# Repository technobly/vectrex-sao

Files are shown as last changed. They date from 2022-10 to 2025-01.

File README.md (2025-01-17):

# Vectrex SAO

Hardware and software files for the mini playable Vectrex SAO by Brett Walach.  Made for Hackaday Supercon 2022!

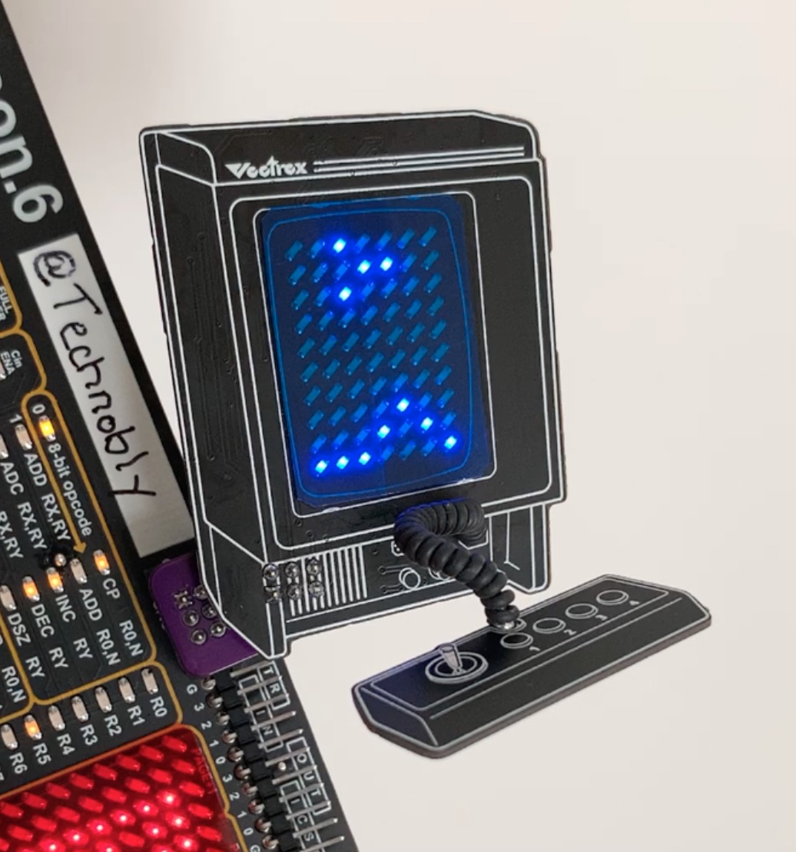
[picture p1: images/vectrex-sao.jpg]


# Features
- Mini playable low res version of Scramble
- 7 x 10 White LED Charlieplexed display (placed in a slight perspective to match the Vectrex artwork!)
- Joystick is a 1-button capacitive touch controller
- PIC16F886 8K MCU (I had a reel of these I pulled out of the trash, which is why it uses this relatively old and huge MCU.)
- Speaker (auto mutes if not playing, or can permanently disable with removing a solder blob)
- Coily cord!  This is made of a solid core silicone wire, and stranded core silicone wire.  These were an absolute pain to make.
- Jumpers for hacking, control it via I2C directly if you want from a main badge... and there's PWM input for the speaker and touch controller output for sensing button presses available to wire to the SAO connector.
- What's a Vectrex? [https://wikipedia.org/wiki/Vectrex](https://wikipedia.org/wiki/Vectrex)
- **High score permanently saved!** Tweet a pic of your score @Technobly #vectrex-sao #supercon #badgelife

# BOM

- PCBs: 1.0mm, HASL finish, white silkscreen, black soldermask, gives a nice thin feel to them. NOTE: 1.0mm is thinner than standard PCBs!
- Don't forget to order both PCBs: 1) the main [console body](gerbers/vectrex-sao-v1.1.zip) and 2) the [controller](gerbers/vectrex-sao-controller-v1.1.zip)
- [bom/vectrex-sao-bom-both-sides.csv](bom/vectrex-sao-bom-both-sides.csv) contains all parts required to build the SAO, ready to upload to JLCPCB
- [bom/vectrex-sao-pos-both-sides.csv](bom/vectrex-sao-pos-both-sides.csv) contains the position of all parts required, ready to upload to JLCPCB
- Inner coily cord wire - 18 AWG solid core, black PVC jacket, outer diameter 1.6mm, 2.0" long with 0.25" stripped on both ends for a 1.5" long jacket. [Digikey 10982-18-1-2000-001-1-TD](https://www.digikey.com/en/products/detail/cnc-tech/10982-18-1-2000-001-1-TD/12749485)
- Outer coily cord wire - 26 AWG stranded core, black silicone jacket, outer diameter 1.3mm, ~27 turns, ~9" long. [Digikey 1175-3132-26-1-0500-001-1-TS-DS-ND](https://www.digikey.com/en/products/detail/cnc-tech/3132-26-1-0500-001-1-TS/15853654)

# Coily Cord Construction

#### 1. Wrap the 26 AWG stranded silicone wire around the 0.25" stripped end of the 18 AWG solid wire, but do not solder it yet.

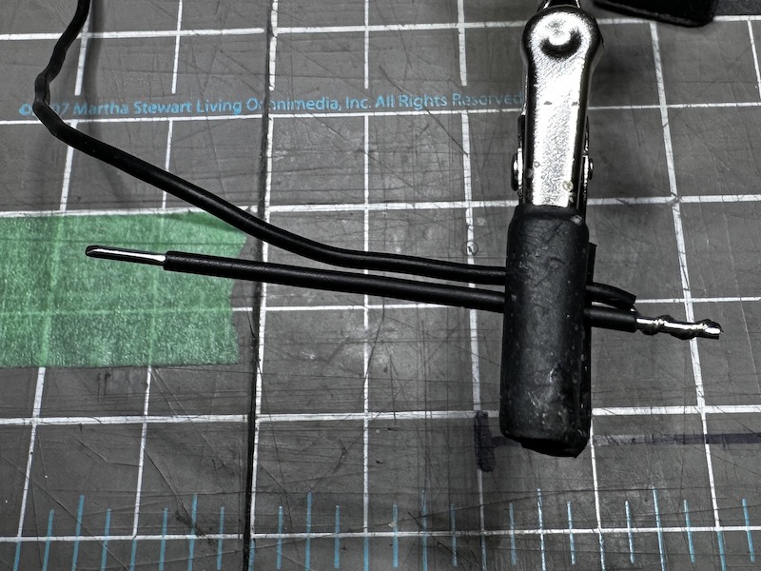
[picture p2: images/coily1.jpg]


#### 2. Add the controller PCB observing the proper orientation.

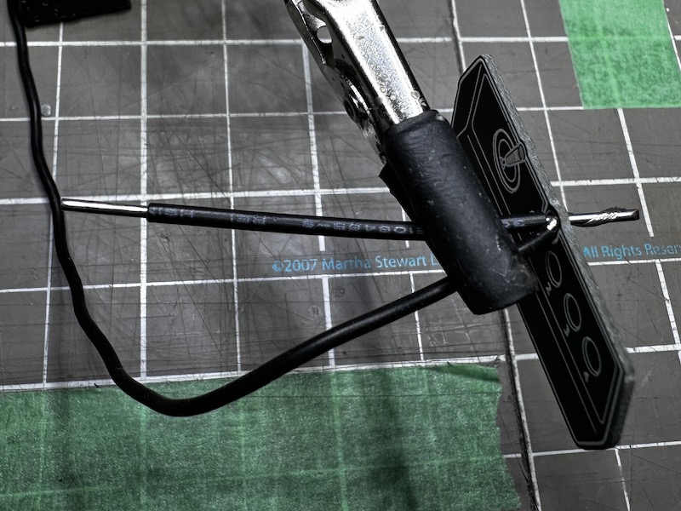
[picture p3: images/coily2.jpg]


#### 3. Add a good amount of solder here, and push the board up against the wire bundle if possible (I did not push it up in this picture like I should have).

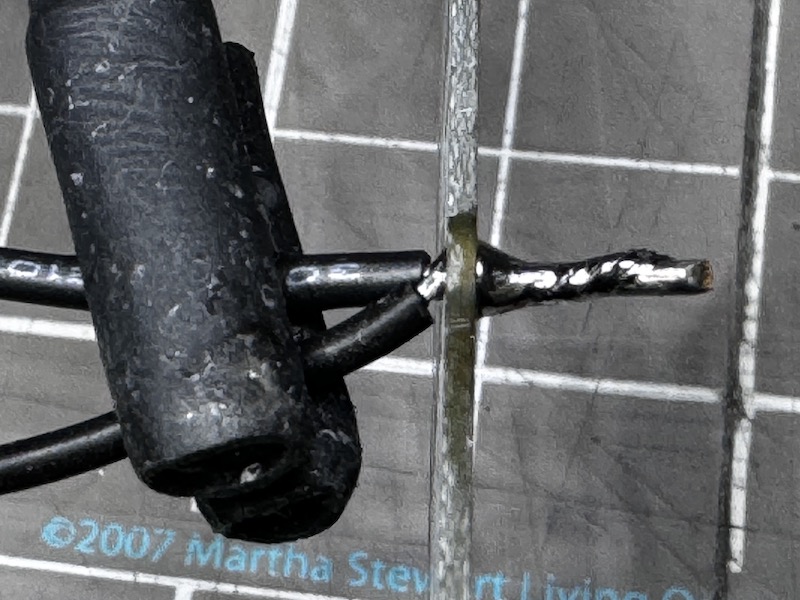
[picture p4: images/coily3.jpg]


#### 4. Flush cut the excess wire, but leave a bit sticking out so has a little mechanical strength.

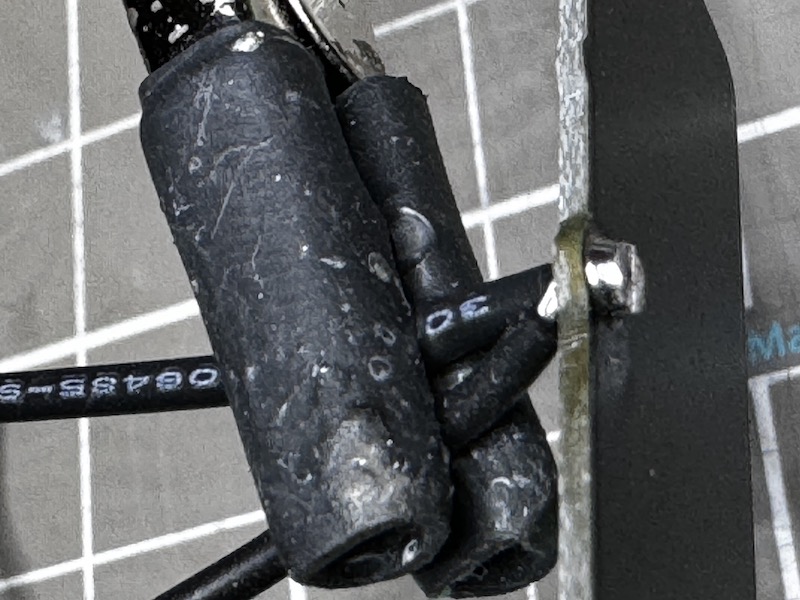
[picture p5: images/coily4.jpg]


#### 5. Wrap the silicone wire 21-27 times (21 if diameter is 1.5mm, 27 if 1.3mm).  Wrap the wire tightly and keep pushing it down on the solid core as you go.  Finally twist the stranded wires around the end and while holding that tightly, clamp the wire bundle to prevent it from unwinding.

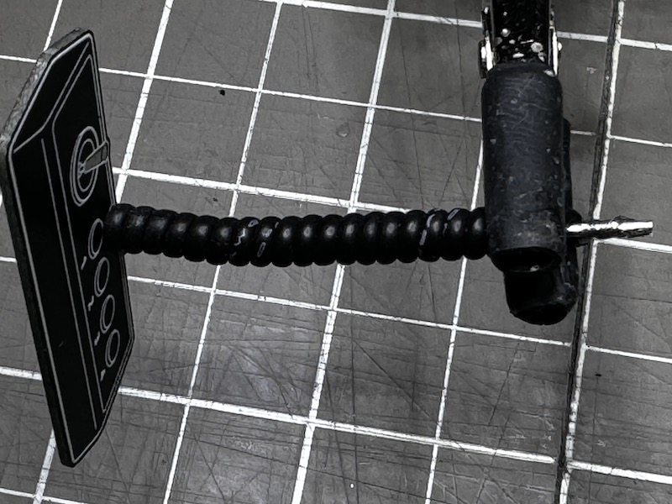
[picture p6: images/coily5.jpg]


#### 6. Now add the main PCB obsererving the correct orientation.

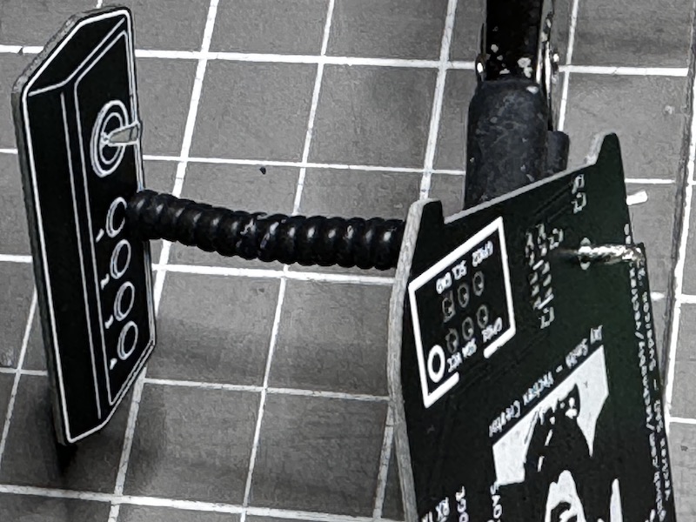
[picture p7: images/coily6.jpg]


#### 7. Add a good amount of solder here as well. Flush cut the excess wire, but leave a bit sticking out so has a little mechanical strength.

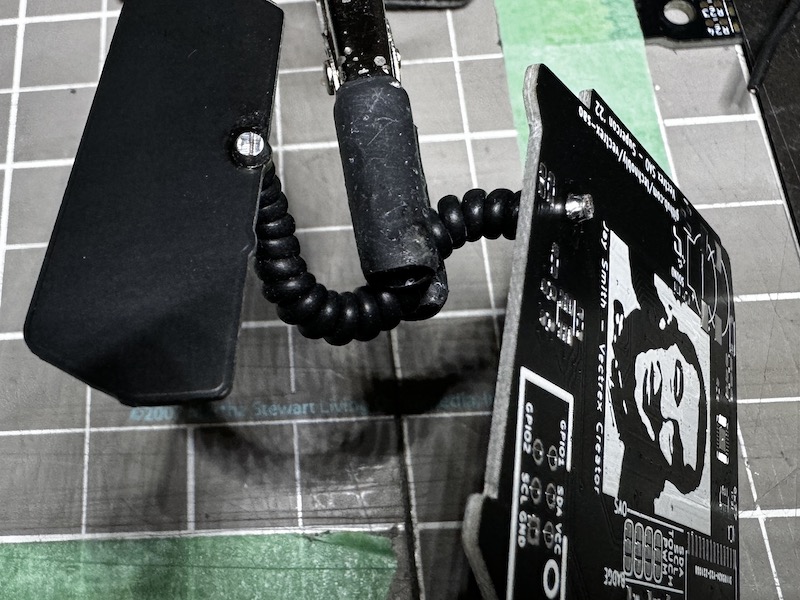
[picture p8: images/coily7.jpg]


#### 8. The one on the left used 1.5mm 26 AWG wire so it has 21 wraps, and the one on the right has a slightly smaller diameter wire 1.3mm so it requires 27 wraps.  Both will work fine, but 27 wraps looks a little closer to reality :smile:

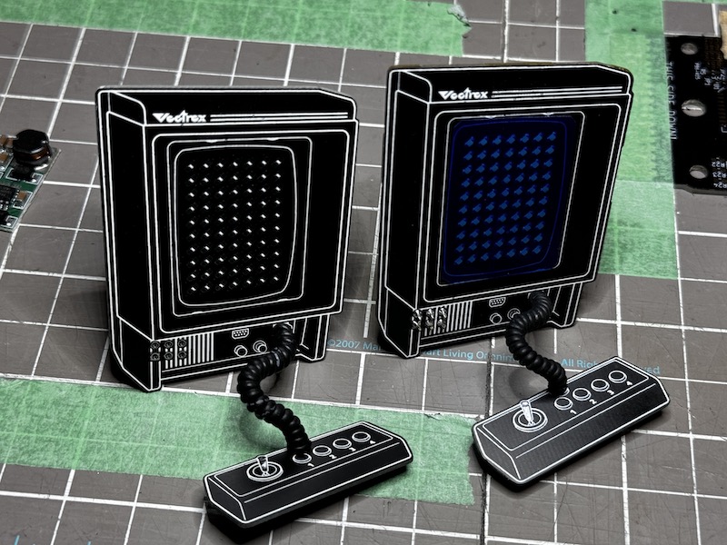
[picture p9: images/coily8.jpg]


# Video of it in action:

[Youtube.com/PlayVectrex](https://youtu.be/AfYQyKARwps?si=DoC_TBigiWhMu1rB)

# License

Creative Commons Attribution-ShareAlike 4.0 International (CC BY-SA 4.0) - essentially do whatever you want, and if this is helpful to you [consider buying me a coffee](https://buymeacoffee.com/walach)  Full [LICENSE here](LICENSE)

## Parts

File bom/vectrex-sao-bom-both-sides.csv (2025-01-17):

Comment | Designator | Footprint | Part Number
LED 0603 | C1-1 | LED_0603_1608Metric | C434422
LED 0603 | C1-2 | LED_0603_1608Metric | C434422
LED 0603 | C1-3 | LED_0603_1608Metric | C434422
LED 0603 | C1-4 | LED_0603_1608Metric | C434422
LED 0603 | C1-5 | LED_0603_1608Metric | C434422
LED 0603 | C1-6 | LED_0603_1608Metric | C434422
LED 0603 | C1-7 | LED_0603_1608Metric | C434422
LED 0603 | C2-1 | LED_0603_1608Metric | C434422
LED 0603 | C2-2 | LED_0603_1608Metric | C434422
LED 0603 | C2-3 | LED_0603_1608Metric | C434422
LED 0603 | C2-4 | LED_0603_1608Metric | C434422
LED 0603 | C2-5 | LED_0603_1608Metric | C434422
LED 0603 | C2-6 | LED_0603_1608Metric | C434422
LED 0603 | C2-7 | LED_0603_1608Metric | C434422
LED 0603 | C3-1 | LED_0603_1608Metric | C434422
LED 0603 | C3-2 | LED_0603_1608Metric | C434422
LED 0603 | C3-3 | LED_0603_1608Metric | C434422
LED 0603 | C3-4 | LED_0603_1608Metric | C434422
LED 0603 | C3-5 | LED_0603_1608Metric | C434422
LED 0603 | C3-6 | LED_0603_1608Metric | C434422
LED 0603 | C3-7 | LED_0603_1608Metric | C434422
LED 0603 | C4-1 | LED_0603_1608Metric | C434422
LED 0603 | C4-2 | LED_0603_1608Metric | C434422
LED 0603 | C4-3 | LED_0603_1608Metric | C434422
LED 0603 | C4-4 | LED_0603_1608Metric | C434422
LED 0603 | C4-5 | LED_0603_1608Metric | C434422
LED 0603 | C4-6 | LED_0603_1608Metric | C434422
LED 0603 | C4-7 | LED_0603_1608Metric | C434422
LED 0603 | C5-1 | LED_0603_1608Metric | C434422
LED 0603 | C5-2 | LED_0603_1608Metric | C434422
LED 0603 | C5-3 | LED_0603_1608Metric | C434422
LED 0603 | C5-4 | LED_0603_1608Metric | C434422
LED 0603 | C5-5 | LED_0603_1608Metric | C434422
LED 0603 | C5-6 | LED_0603_1608Metric | C434422
LED 0603 | C5-7 | LED_0603_1608Metric | C434422
LED 0603 | C6-1 | LED_0603_1608Metric | C434422
LED 0603 | C6-2 | LED_0603_1608Metric | C434422
LED 0603 | C6-3 | LED_0603_1608Metric | C434422
LED 0603 | C6-4 | LED_0603_1608Metric | C434422
LED 0603 | C6-5 | LED_0603_1608Metric | C434422
LED 0603 | C6-6 | LED_0603_1608Metric | C434422
LED 0603 | C6-7 | LED_0603_1608Metric | C434422
LED 0603 | C7-1 | LED_0603_1608Metric | C434422
LED 0603 | C7-2 | LED_0603_1608Metric | C434422
LED 0603 | C7-3 | LED_0603_1608Metric | C434422
LED 0603 | C7-4 | LED_0603_1608Metric | C434422
LED 0603 | C7-5 | LED_0603_1608Metric | C434422
LED 0603 | C7-6 | LED_0603_1608Metric | C434422
LED 0603 | C7-7 | LED_0603_1608Metric | C434422
LED 0603 | C7-8 | LED_0603_1608Metric | C434422
LED 0603 | C7-9 | LED_0603_1608Metric | C434422
LED 0603 | C7-10 | LED_0603_1608Metric | C434422
LED 0603 | C7-11 | LED_0603_1608Metric | C434422
LED 0603 | C7-12 | LED_0603_1608Metric | C434422
LED 0603 | C7-13 | LED_0603_1608Metric | C434422
LED 0603 | C7-14 | LED_0603_1608Metric | C434422
LED 0603 | C8-1 | LED_0603_1608Metric | C434422
LED 0603 | C8-2 | LED_0603_1608Metric | C434422
LED 0603 | C8-3 | LED_0603_1608Metric | C434422
LED 0603 | C8-4 | LED_0603_1608Metric | C434422
LED 0603 | C8-5 | LED_0603_1608Metric | C434422
LED 0603 | C8-6 | LED_0603_1608Metric | C434422
LED 0603 | C8-7 | LED_0603_1608Metric | C434422
LED 0603 | C8-8 | LED_0603_1608Metric | C434422
LED 0603 | C8-9 | LED_0603_1608Metric | C434422
LED 0603 | C8-10 | LED_0603_1608Metric | C434422
LED 0603 | C8-11 | LED_0603_1608Metric | C434422
LED 0603 | C8-12 | LED_0603_1608Metric | C434422
LED 0603 | C8-13 | LED_0603_1608Metric | C434422
LED 0603 | C8-14 | LED_0603_1608Metric | C434422
10uF 0805 | C1 | Capacitor_SMD:C_0805_2012Metric | C1713
10uF 0805 | C2 | Capacitor_SMD:C_0805_2012Metric | C1713
0.1uF 0805 | C3 | Capacitor_SMD:C_0805_2012Metric | C49678
0.1uF 0805 | C4 | Capacitor_SMD:C_0805_2012Metric | C49678
0.1uF 0603 | C5 | Capacitor_SMD:C_0603_1608Metric | C282519
22pF 0603 | C6 | Capacitor_SMD:C_0603_1608Metric | C105620
Diode MBR0520 | D1 | Diode_SMD:D_SOD-123 | C116159
2x3 Male Shrouded Pin Header BHR-06-VUA | J2 | vectrex-sao:Badgelife-SAOv169-SAO-2x3 | 2057-BHR-06-VUA-ND
LED 0603 | LED1 | vectrex-sao:LED_0603_1608Metric | C434422
Speaker FUET-9032-05 | LS1 | vectrex-sao:MagneticBuzzer_FUET-9032-05 | C2690510
NPN MMBT3904 | Q1 | Package_TO_SOT_SMD:SOT-23 | C2688228
10k x 4 array | R1 | vectrex-sao:R_Array_Convex_4x0603_CAT16-F4 | C69593
10k 0603 | R2 | Resistor_SMD:R_0603_1608Metric | C2930027
10k 0603 | R6 | Resistor_SMD:R_0603_1608Metric | C2930027
1k 0603 | R3 | Resistor_SMD:R_0603_1608Metric | C2907113
1k 0603 | R4 | Resistor_SMD:R_0603_1608Metric | C2907113
1k 0603 | R5 | Resistor_SMD:R_0603_1608Metric | C2907113
PIC16F886-I/SO | U1 | Package_SO:SOIC-28W_7.5x17.9mm_P1.27mm | PIC16F886-I/SO-ND
LED Controller IS31FL3731-QFLS2 | U2 | Package_DFN_QFN:QFN-28-1EP_4x4mm_P0.4mm_EP2.3x2.3mm | C191206
TC233A | U3 | Package_TO_SOT_SMD:SOT-23-6 | C2798022

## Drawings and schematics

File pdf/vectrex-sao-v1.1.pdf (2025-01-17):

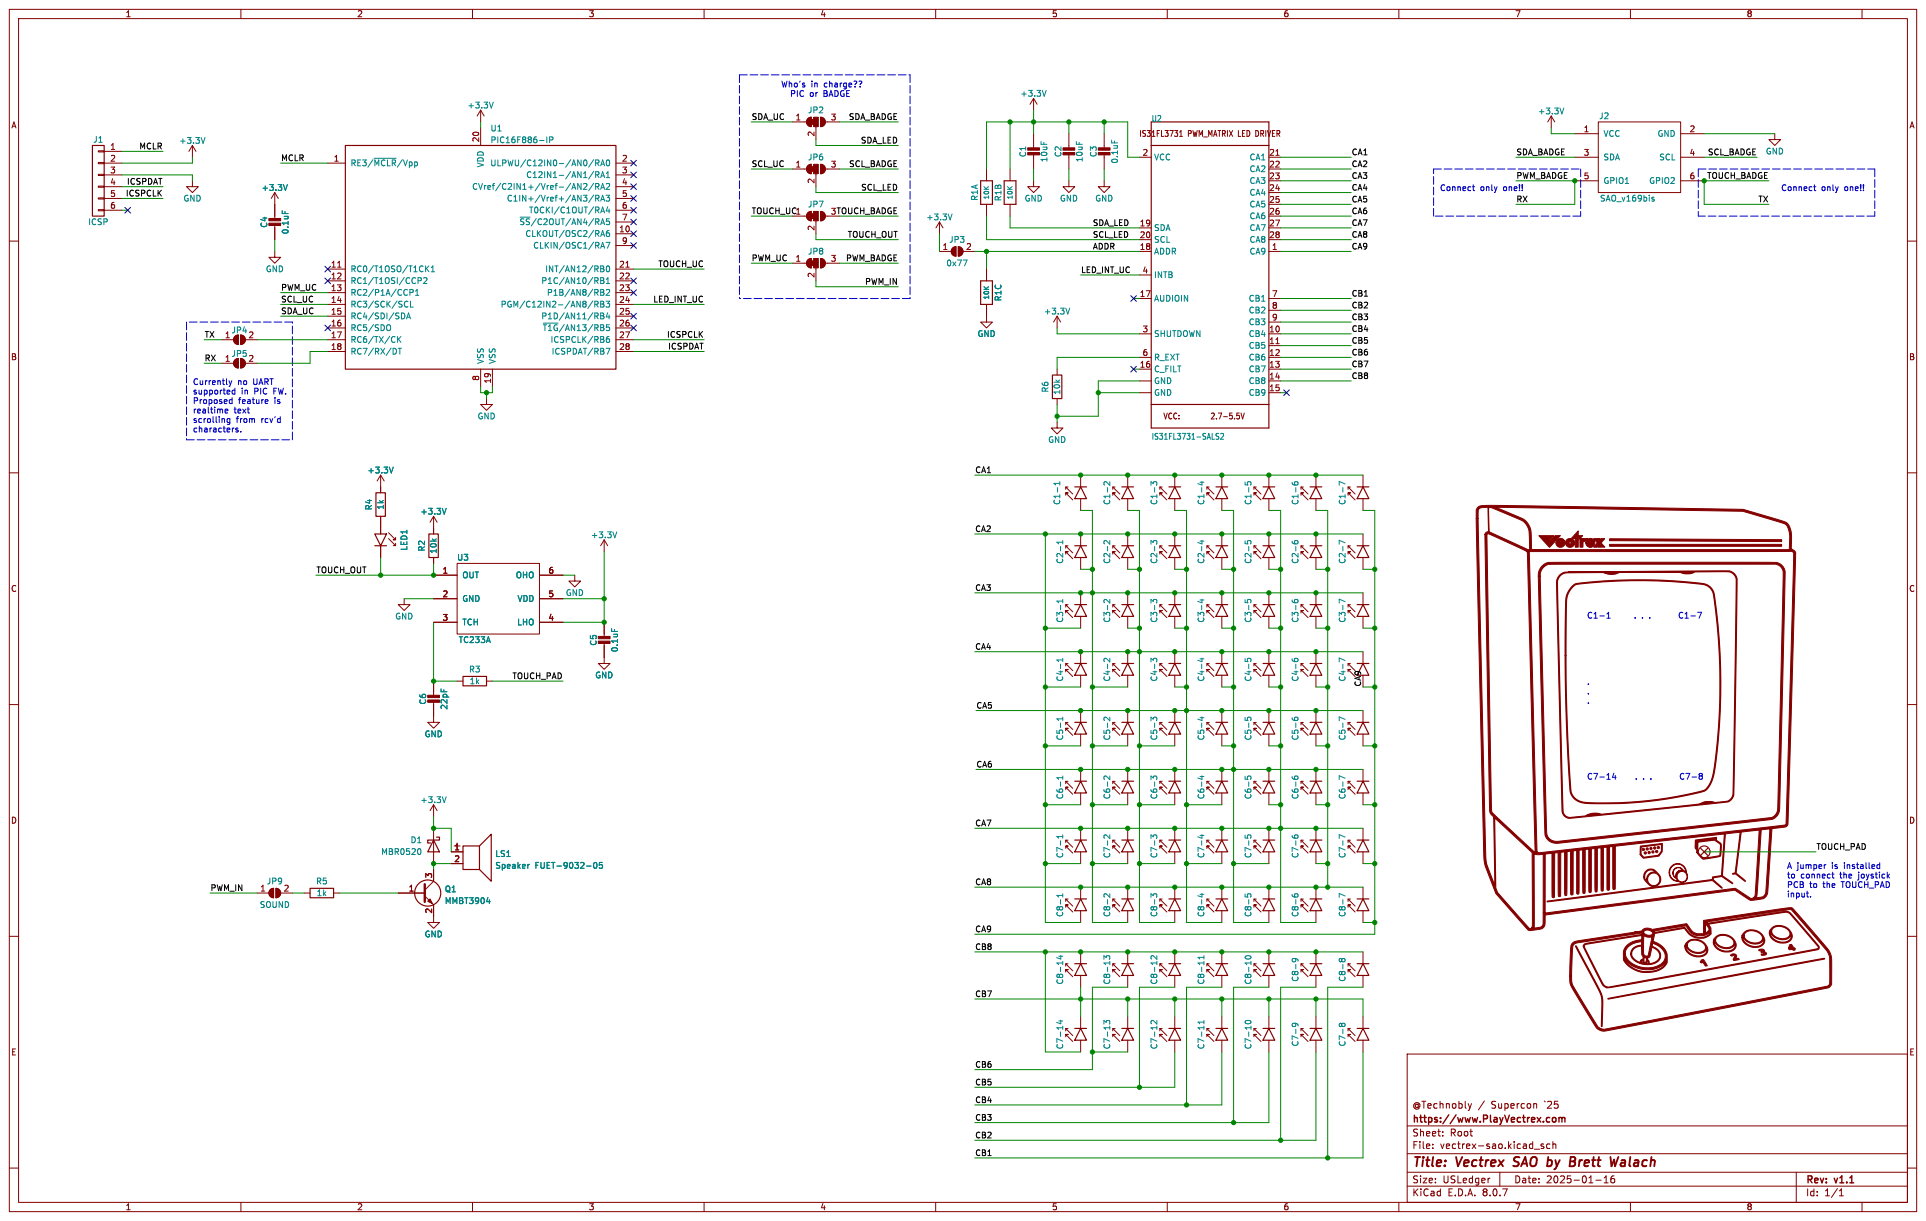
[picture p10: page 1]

A jumper is installed
to connect the joystick PCB to the TOUCH_PAD

Id: 1/1 Title: Vectrex SAO by Brett Walach

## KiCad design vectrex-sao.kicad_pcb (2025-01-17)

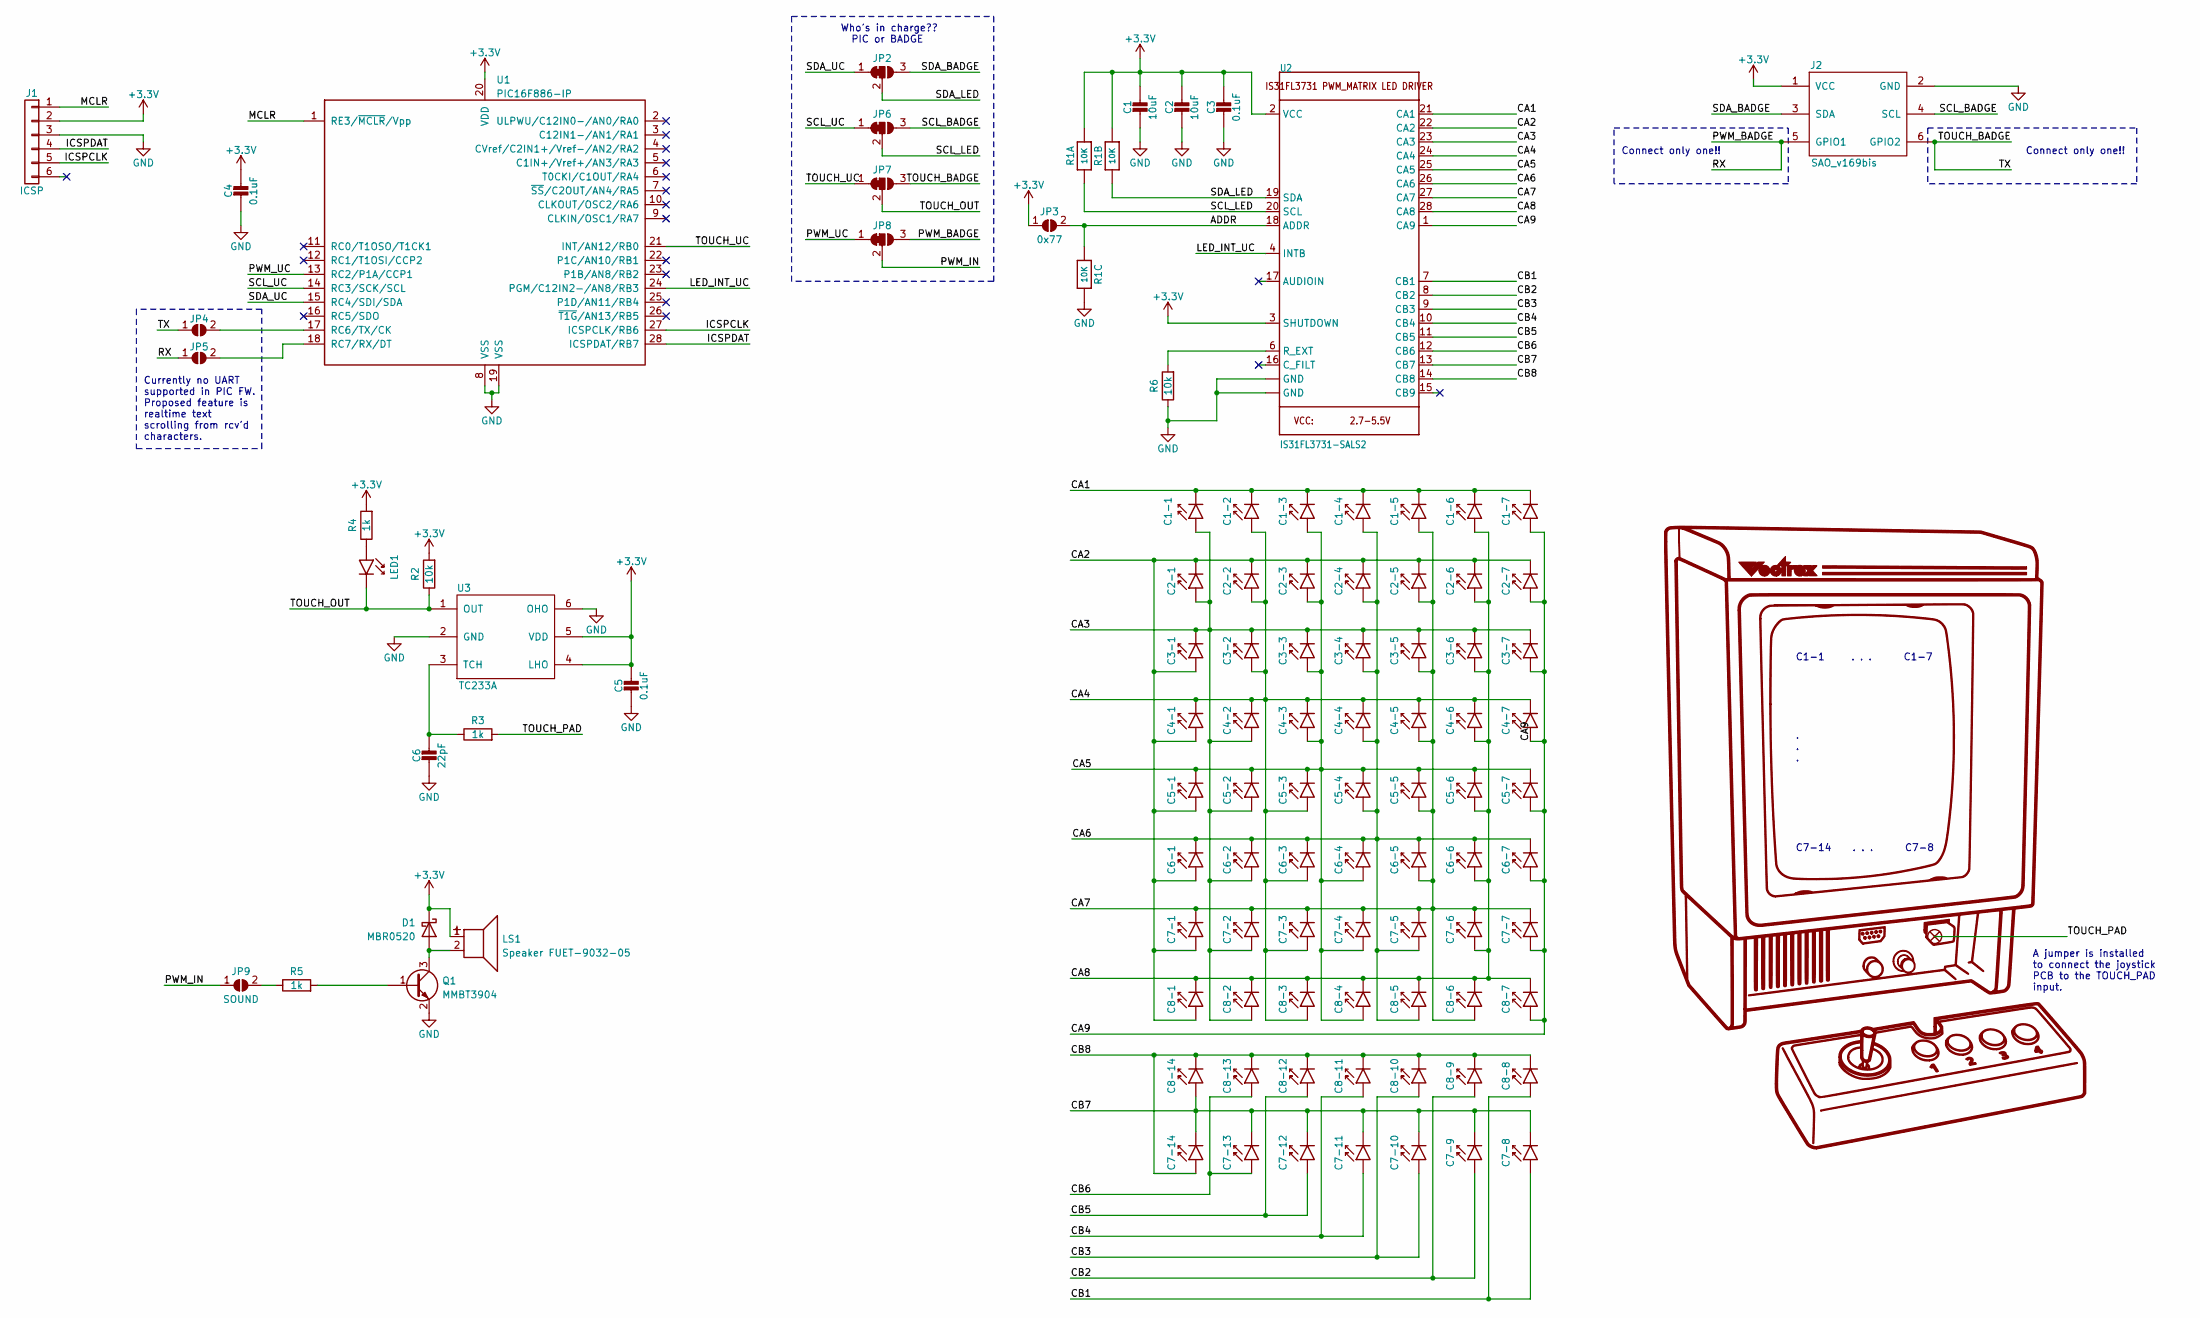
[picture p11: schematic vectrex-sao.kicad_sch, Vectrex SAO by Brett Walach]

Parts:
C1, C2: 10uF; C_0805_2012Metric
C1-1, C1-2, C1-3, C1-4, C1-5, C1-6, C1-7, C2-1, C2-2, C2-3, C2-4, C2-5, C2-6, C2-7, C3-1, C3-2, C3-3, C3-4, C3-5, C3-6, C3-7, C4-1, C4-2, C4-3, C4-4, C4-5, C4-6, C4-7, C5-1, C5-2, C5-3, C5-4, C5-5, C5-6, C5-7, C6-1, C6-2, C6-3, C6-4, C6-5, C6-6, C6-7, C7-1, C7-2, C7-3, C7-4, C7-5, C7-6, C7-7, C7-8, C7-9, C7-10, C7-11, C7-12, C7-13, C7-14, C8-1, C8-2, C8-3, C8-4, C8-5, C8-6, C8-7, C8-8, C8-9, C8-10, C8-11, C8-12, C8-13, C8-14: LED0603_NOOUTLINE; LED_0603_1608Metric
C3, C4: 0.1uF; C_0805_2012Metric
C5: 0.1uF; C_0603_1608Metric
C6: 22pF; C_0603_1608Metric
D1: MBR0520; D_SOD-123
J1: ICSP; PinHeader_1x06_P2.54mm_Vertical_SMD_Pin1Right
J2: SAO_v169bis; Badgelife-SAOv169-SAO-2x3
JP1: TOUCH_PAD; MountingHole_1.5mm_M2_Pad_TopOnly
JP2, JP6, JP7, JP8: solderjumper-3way; SolderJumper-3_P1.3mm_Bridged12_RoundedPad1.0x1.5mm_NumberL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
JP3: 0x77; SolderJumper-2_P1.3mm_Open_RoundedPad1.0x1.5mm
JP4: TX; SolderJumper-2_P1.3mm_Open_RoundedPad1.0x1.5mm
JP5: RX; SolderJumper-2_P1.3mm_Open_RoundedPad1.0x1.5mm
JP9: SOUND; SolderJumper-2_P1.3mm_Bridged_RoundedPad1.0x1.5mm
LED1: LED0603_NOOUTLINE; LED_0603_1608Metric
LS1: Speaker FUET-9032-05; MagneticBuzzer_FUET-9032-05
Q1: MMBT3904; SOT-23
R1: 10K; R_Array_Convex_4x0603_CAT16-F4
R2, R6: 10k; R_0603_1608Metric
R3, R4, R5: 1k; R_0603_1608Metric
U1: PIC16F886-IP; SOIC-28W_7.5x17.9mm_P1.27mm
U2: IS31FL3731-SALS2; QFN-28-1EP_4x4mm_P0.4mm_EP2.3x2.3mm
U3: TC233A; SOT-23-6

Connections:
+3.3V: C1.1, C2.1, C3.1, C4.1, C5.1, D1.1 (K), J1.2, J2.1 (VCC), JP3.1 (A), LS1.1, R1.7 (2), R1.8 (2), R2.2, R4.2, U1.20 (VDD), U2.2 (VCC), U2.3 (SHUTDOWN), U3.4 (LHO), U3.5 (VDD)
/ADDR: JP3.2 (B), R1.3 (1), U2.18 (ADDR)
/CA1: C1-1.1 (K), C1-2.1 (K), C1-3.1 (K), C1-4.1 (K), C1-5.1 (K), C1-6.1 (K), C1-7.1 (K), U2.21 (CA1)
/CA2: C2-1.1 (K), C2-2.1 (K), C2-3.1 (K), C2-4.1 (K), C2-5.1 (K), C2-6.1 (K), C2-7.1 (K), C3-1.2 (A), C4-1.2 (A), C5-1.2 (A), C6-1.2 (A), C7-1.2 (A), C8-1.2 (A), U2.22 (CA2)
/CA3: C1-1.2 (A), C2-1.2 (A), C3-1.1 (K), C3-2.1 (K), C3-3.1 (K), C3-4.1 (K), C3-5.1 (K), C3-6.1 (K), C3-7.1 (K), C4-2.2 (A), C5-2.2 (A), C6-2.2 (A), C7-2.2 (A), C8-2.2 (A), U2.23 (CA3)
/CA4: C1-2.2 (A), C2-2.2 (A), C3-2.2 (A), C4-1.1 (K), C4-2.1 (K), C4-3.1 (K), C4-4.1 (K), C4-5.1 (K), C4-6.1 (K), C4-7.1 (K), C5-3.2 (A), C6-3.2 (A), C7-3.2 (A), C8-3.2 (A), U2.24 (CA4)
/CA5: C1-3.2 (A), C2-3.2 (A), C3-3.2 (A), C4-3.2 (A), C5-1.1 (K), C5-2.1 (K), C5-3.1 (K), C5-4.1 (K), C5-5.1 (K), C5-6.1 (K), C5-7.1 (K), C6-4.2 (A), C7-4.2 (A), C8-4.2 (A), U2.25 (CA5)
/CA6: C1-4.2 (A), C2-4.2 (A), C3-4.2 (A), C4-4.2 (A), C5-4.2 (A), C6-1.1 (K), C6-2.1 (K), C6-3.1 (K), C6-4.1 (K), C6-5.1 (K), C6-6.1 (K), C6-7.1 (K), C7-5.2 (A), C8-5.2 (A), U2.26 (CA6)
/CA7: C1-5.2 (A), C2-5.2 (A), C3-5.2 (A), C4-5.2 (A), C5-5.2 (A), C6-5.2 (A), C7-1.1 (K), C7-2.1 (K), C7-3.1 (K), C7-4.1 (K), C7-5.1 (K), C7-6.1 (K), C7-7.1 (K), C8-6.2 (A), U2.27 (CA7)
/CA8: C1-6.2 (A), C2-6.2 (A), C3-6.2 (A), C4-6.2 (A), C5-6.2 (A), C6-6.2 (A), C7-6.2 (A), C8-1.1 (K), C8-2.1 (K), C8-3.1 (K), C8-4.1 (K), C8-5.1 (K), C8-6.1 (K), C8-7.1 (K), U2.28 (CA8)
/CA9: C1-7.2 (A), C2-7.2 (A), C3-7.2 (A), C4-7.2 (A), C5-7.2 (A), C6-7.2 (A), C7-7.2 (A), C8-7.2 (A), U2.1 (CA9)
/CB1: C7-8.2 (A), C8-8.2 (A), U2.7 (CB1)
/CB2: C7-9.2 (A), C8-9.2 (A), U2.8 (CB2)
/CB3: C7-10.2 (A), C8-10.2 (A), U2.9 (CB3)
/CB4: C7-11.2 (A), C8-11.2 (A), U2.10 (CB4)
/CB5: C7-12.2 (A), C8-12.2 (A), U2.11 (CB5)
/CB6: C7-13.2 (A), C8-13.2 (A), U2.12 (CB6)
/CB7: C7-8.1 (K), C7-9.1 (K), C7-10.1 (K), C7-11.1 (K), C7-12.1 (K), C7-13.1 (K), C7-14.1 (K), C8-14.2 (A), U2.13 (CB7)
/CB8: C7-14.2 (A), C8-8.1 (K), C8-9.1 (K), C8-10.1 (K), C8-11.1 (K), C8-12.1 (K), C8-13.1 (K), C8-14.1 (K), U2.14 (CB8)
/ICSPCLK: J1.5, U1.27 (ICSPCLK/RB6)
/ICSPDAT: J1.4, U1.28 (ICSPDAT/RB7)
/LED_INT_UC: U1.24 (PGM/C12IN2-/AN8/RB3), U2.4 (INTB)
/MCLR: J1.1, U1.1 (RE3/~MCLR/Vpp)
/PWM_BADGE: J2.5 (GPIO1), JP5.1 (A), JP8.3 (B)
/PWM_IN: JP8.2 (C), JP9.1 (A)
/PWM_UC: JP8.1 (A), U1.13 (RC2/P1A/CCP1)
/SCL_BADGE: J2.4 (SCL), JP6.3 (B)
/SCL_LED: JP6.2 (C), R1.1, U2.20 (SCL)
/SCL_UC: JP6.1 (A), U1.14 (RC3/SCK/SCL)
/SDA_BADGE: J2.3 (SDA), JP2.3 (B)
/SDA_LED: JP2.2 (C), R1.2 (1), U2.19 (SDA)
/SDA_UC: JP2.1 (A), U1.15 (RC4/SDI/SDA)
/TOUCH_BADGE: J2.6 (GPIO2), JP4.1 (A), JP7.3 (B)
/TOUCH_OUT: JP7.2 (C), LED1.1 (K), R2.1, U3.1 (OUT)
/TOUCH_PAD: JP1.1 (TP), R3.2
/TOUCH_UC: JP7.1 (A), U1.21 (INT/AN12/RB0)
GND: C1.2, C2.2, C3.2, C4.2, C5.2, C6.2, J1.3, J2.2 (GND), Q1.2 (E), R1.6 (2), R6.1, U1.8 (VSS), U1.19 (VSS), U2.5 (GND), U2.29 (GND), U3.2 (GND), U3.6 (OHO)
unnamed: D1.2 (A), LS1.2, Q1.3 (C)
unnamed: JP4.2 (B), U1.17 (RC6/TX/CK)
unnamed: JP5.2 (B), U1.18 (RC7/RX/DT)
unnamed: JP9.2 (B), R5.1
unnamed: LED1.2 (A), R4.1
unnamed: Q1.1 (B), R5.2
unnamed: R6.2, U2.6 (R_EXT)
unnamed: C6.1, R3.1, U3.3 (TCH)

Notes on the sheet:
Who's in charge?? PIC or BADGE
A jumper is installed to connect the joystick PCB to the TOUCH_PAD input.
Connect only one!!
Currently no UART supported in PIC FW. Proposed feature is realtime text scrolling from rcv'd characters.
C1-1 . . . C1-7 . . . C7-14 . . . C7-8

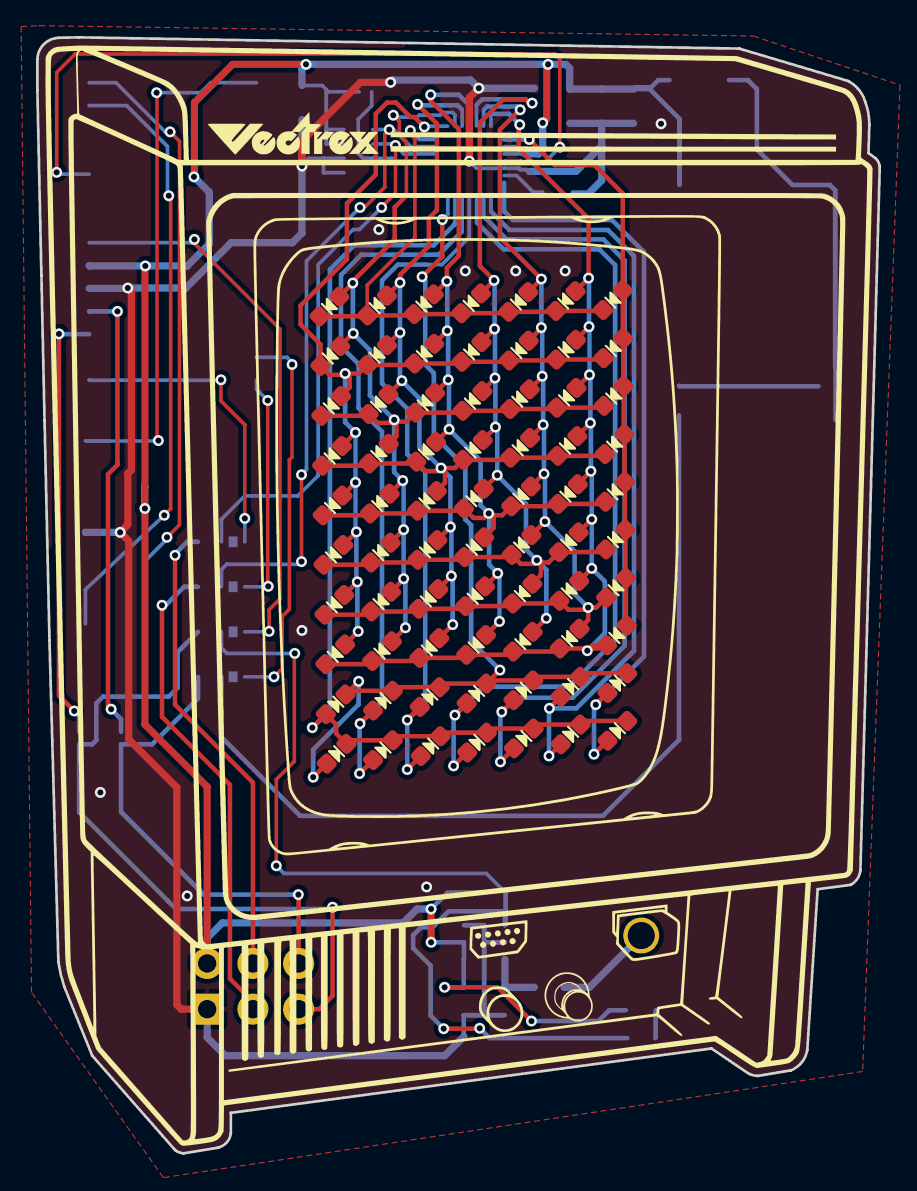
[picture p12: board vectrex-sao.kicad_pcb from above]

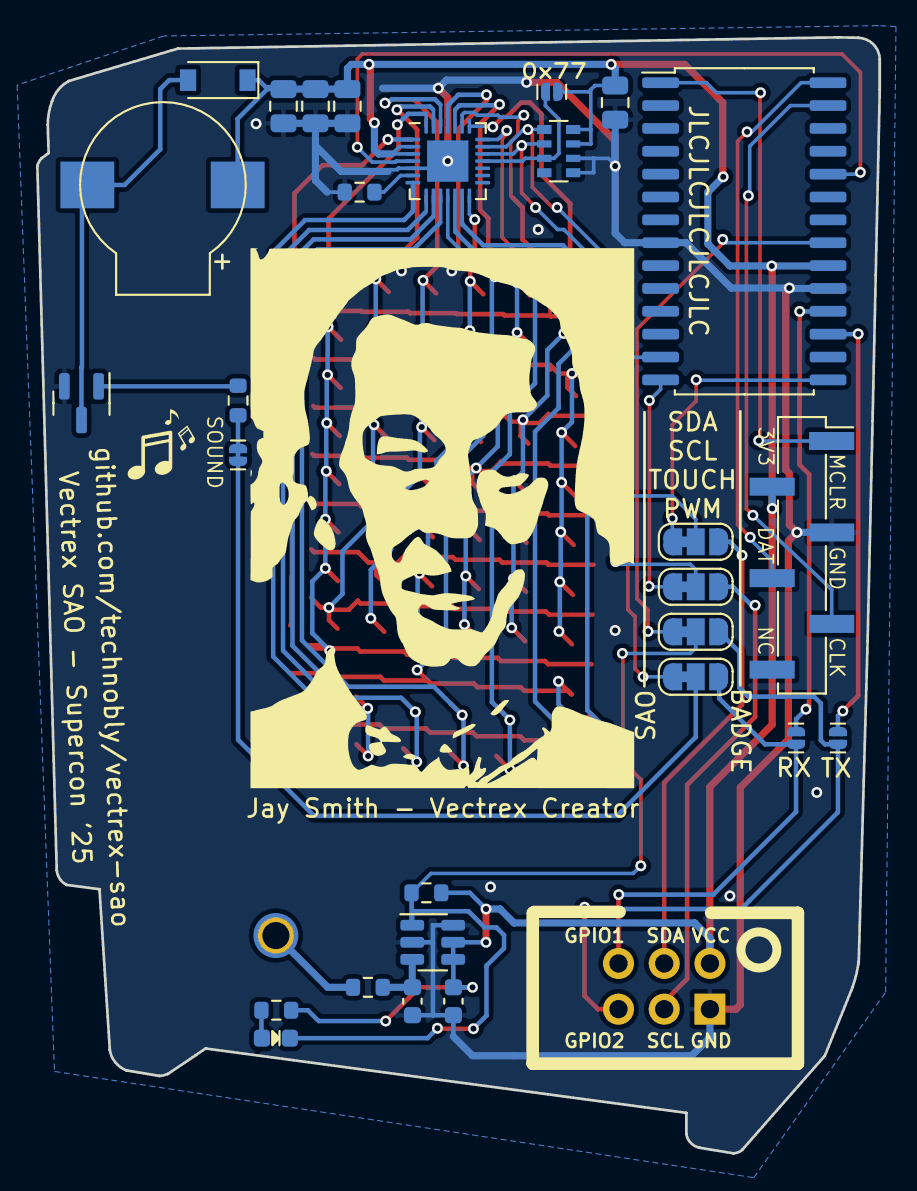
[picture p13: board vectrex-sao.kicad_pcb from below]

Board: 2 copper layers, 46.8 x 62.0 mm, 100 parts (29 on the bottom side), 45 nets.

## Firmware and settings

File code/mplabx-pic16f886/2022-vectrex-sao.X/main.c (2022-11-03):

/*
 * File:   main.c
 * Author: Brett Walach
 *
 * Created on September 23, 2022, 4:42 PM
 */

#include <xc.h>
#include "config.h"
#include "IS31FL3731.h"
#include <stdlib.h>
#include <stdio.h>
#include <time.h>
#include "notes.h"
#include "sound.h"
#include "sprite.h"
#include "eeprom.h"

// This would be the best octave, but we can't go that low
//uint16_t song_vec_startup[] = { 0,1500, A3,232, 0,10, A3,116, G4,1200, 0,2000, 1,1 }; // 1,1 is end of song
uint16_t song_vec_startup[] = { 0,1500, A4,232, 0,10, A4,116, G5,1200, 0,2000, 1,1 }; // 1,1 is end of song

// 3x4 number font
const uint8_t num3by4[] = {
    0b00000111, // 0
    0b00000101,
    0b00000101,
    0b00000111,
    0b00000001, // 1
    0b00000001,
    0b00000001,
    0b00000001,
    0b00000111, // 2
    0b00000010,
    0b00000100,
    0b00000111,
    0b00000111, // 3
    0b00000010,
    0b00000001,
    0b00000111,
    0b00000101, // 4
    0b00000111,
    0b00000001,
    0b00000001,
    0b00000111, // 5
    0b00000110,
    0b00000001,
    0b00000111,
    0b00000011, // 6
    0b00000110,
    0b00000101,
    0b00000111,
    0b00000111, // 7
    0b00000001,
    0b00000010,
    0b00000100,
    0b00000111, // 8
    0b00000010,
    0b00000101,
    0b00000111,
    0b00000111, // 9
    0b00000101,
    0b00000011,
    0b00000110,
};

// 3x4 number font (blank))
const uint8_t num3by4_blank[] = {
    0b01110111, // BLANK
    0b01110111,
    0b01110111,
    0b01110111,
};

// Pattern to blank out 3 lines
const uint8_t blank_3[] = {
    0b01111111, // BLANK
    0b01111111,
    0b01111111,
};

// ship
uint8_t sprite1[] = {
    3,
    6,
    0,
    0b00000001, // 1000000 (shifted down 0)
    0b01100000, // 0110000
    0b00000001  // 1000000
};
// mountain base
uint8_t sprite2[] = {
    3,
    0,
    7,
    0b00000100, // 0000100 (shifted down 7)
    0b00001010, // 0001010
    0b01110001  // 1110001
};
// ship thrust
uint8_t sprite3[] = {
    1,
    6,
    1,
    0b00000001, // 1000000 (shifted down 1)
};
// ship bomb
uint8_t sprite4[] = {
    1,
    6,
    2,
    0b01000000, // 0100000 (shifted down 1)
};
// ship explosion animation (copy offsets from ship)
const uint8_t shipExplosion[] = {
//  0b00000001, // 1000000 (shifted down 0)
//  0b01100000, // 0110000
//  0b00000001  // 1000000
    
    0b00000001, // frame 1
    0b01000000, 
    0b00000000,
    0b00100000,
    0b00000001,
    
    0b01000000, // frame 2
    0b00000000, 
    0b00000000,
    0b00000000,
    0b00100000,
    
    0b00000000, // frame 3
    0b00000000, 
    0b00000000,
    0b00000000,
    0b00000000,
};
// next
uint8_t nextSprite[] = {
    5,
    0,
    0,
    0b01000100, // 010100 (shifted down 3)
    0b00100010, // 001010
    0b00010001, // 000101
    0b00100010, // 001010
    0b01000100, // 010100
};

// high score "HI"
const uint8_t highScoreText[] = {
    0b01010111, // 1010111 (shifted down 7)
    0b01110010, // 1110010
    0b01010010, // 1010010
    0b01010111, // 1010111
};

uint8_t temp;
uint8_t touchPressed = 1;
uint8_t toggleLed = 0;
uint8_t portbTemp = 0;  // variable to use as PORTB dump
uint8_t startupOnce = 0;
uint8_t highscoreOnBoot = 1;

void main(void) {
    ledBegin(ISSI_ADDR_DEFAULT << 1);
    
    srand((int)0x55);   // Seed the random number generator
 
    TRISB0 = 1;         // RB0 as Input PIN
    ANSEL = 0;          // DISABLE ANALOG FUNCTION ON PORTB
    ANSELH = 0;         // DISABLE ANALOG FUNCTION ON PORTB
    C1ON = 0;
    C2ON = 0;
    nRBPU = 0;          // Enable Global WPUB
    WPUB0 = 1;          // Enable WPUB for RB0
    
    // SUPER LOOP
    while (1) {
        
    // STARTUP SCREEN
    while(1) {
        static uint8_t counter = 0;
        static uint8_t dwell_count = 0;

        if (++dwell_count & 1) {
            // BOTTOM
            static uint8_t brightness = 30;
            for (uint8_t x = 0; x < 7; x++) {
                temp = (x + counter) % 4;
                if (temp == 0) {
                    ledDrawPixel(9, x, brightness);
                } else {
                    ledDrawPixel(9, x, 0);
                }
            }
            // RIGHT
            for (uint8_t y = 0; y < 10; y++) {
                temp = (y - counter) % 4;
                if (temp == 0) {
                    ledDrawPixel(y, 6, brightness);
                } else {
                    ledDrawPixel(y, 6, 0);
                }
            }
            // TOP
            for (uint8_t x = 0; x < 7; x++) {
                temp = (x - counter) % 4;
                if (temp == 0) {
                    ledDrawPixel(0, x, brightness);
                } else {
                    ledDrawPixel(0, x, 0);
                }
            }
            // LEFT
            for (uint8_t y = 0; y < 10; y++) {
                temp = (y + counter) % 4;
                if (temp == 0) {
                    ledDrawPixel(y, 0, brightness);
                } else {
                    ledDrawPixel(y, 0, 0);
                }
            }
            counter++;
            if (counter > 3) {
                counter = 0;
            }
        } else {
            delay(24); // alternate a delay to slow down the marquee
        }
        if (!startupOnce) {
            if (!playSong(song_vec_startup, 24, 0)) { // 24ms is how long this routine's loop time is
                startupOnce = 1;
                break;
            }
        } else {
            if (!playSong(song_vec_startup, 24, 1)) { // 24ms is how long this routine's loop time is
                break;
            }
        }
    }
    ledClear();
    
    //================
    // SCRAMBLE
    //================
    
    // DEBUG
//    #define SHIP_DWELL_SLOW 255
//    #define SHIP_DWELL_FAST 255
//    #define SHIP_ACCELERATE_DX 60
//    #define SHIP_DECELERATE_DX 60
//    #define BG_ACCELERATE_DX 60
//    #define BG_DECELERATE_DX 60
//    uint8_t bombRate[] = { 1, 1, 1, 1, 1, 1, 1, 1, 1, 1 };
    
    #define SHIP_DWELL_SLOW 60
    #define SHIP_DWELL_FAST 40
    #define SHIP_ACCELERATE_DX 3
    #define SHIP_DECELERATE_DX 1
    #define BG_ACCELERATE_DX 0
    #define BG_DECELERATE_DX 2
    uint8_t bombRate[] = { 1, 1, 4, 2, 1, 1, 1, 1, 1, 1 };

    #define BG_BRIGHTNESS_MAX 60
    #define BG_BRIGHTNESS_MIN 30
    #define THRUST_BRIGHTNESS_MAX 60
    #define THRUST_BRIGHTNESS_MIN 30
    #define BOMB_BRIGHTNESS_MAX 150
    #define BOMB_BRIGHTNESS_MIN 60
    #define SHIP_BRIGHTNESS_MAX 30
    #define SHIP_BRIGHTNESS_MIN 30
    uint8_t moveShip = 0;
    uint8_t dirShip = 1;
    uint8_t dxShip = 1;
    uint8_t dwellShip = 0;
    uint8_t moveBg = 0;
    uint8_t dxBg = 0;
    uint8_t bombActive = 0;
    uint16_t bombNote = 0;
    uint8_t bombCount = 0;
    uint8_t bombHit = 0;
    uint8_t touchCount = 0;
    uint8_t numIndex = 0;
    uint8_t scoreHi = 0;
    uint8_t scoreLo = 0;
    uint8_t highScoreHi = 0;
    uint8_t highScoreLo = 0;
    uint8_t highScoreCount = 0;
    uint8_t highScoreToggle = 1;
    uint8_t scoreCount = 0;
    uint8_t scoreCountGameOver = 0;
    uint8_t fuel = 255;
    uint8_t gameOver = 0;
    uint8_t userInput = 0;

    ledClear();
    highScoreHi = readEEPROM(2);
    highScoreLo = readEEPROM(1);
    if (highScoreHi >= 9 && highScoreLo >= 9) {
        highScoreHi = 0;
        highScoreLo = 0;
        writeEEPROM(1, highScoreLo);
        writeEEPROM(2, highScoreHi);
    }
    if (highscoreOnBoot && (highScoreHi > 0 || highScoreLo > 0)) { // Show high score first boot if there is one
        scoreCountGameOver = 80;
    } else {
        highscoreOnBoot = 0;
    }
    while (1) {
        if (scoreCount) {
            drawObject(num3by4, scoreLo * 4, 4, 0, 3, SHIP_BRIGHTNESS_MIN);
            drawObject(num3by4, scoreHi * 4, 4, 4, 3, SHIP_BRIGHTNESS_MIN);
        } else if (scoreCountGameOver) {
            if (!highscoreOnBoot) {
                drawObject(num3by4, scoreLo * 4, 4, 0, 0, SHIP_BRIGHTNESS_MIN);
                drawObject(num3by4, scoreHi * 4, 4, 4, 0, SHIP_BRIGHTNESS_MIN);
            }
            if (highScoreHi > scoreHi || (highScoreHi == scoreHi && highScoreLo > scoreLo)) {
                if (highscoreOnBoot) {
                    drawObject(num3by4, highScoreLo * 4, 4, 0, 6, SHIP_BRIGHTNESS_MIN);
                    drawObject(num3by4, highScoreHi * 4, 4, 4, 6, SHIP_BRIGHTNESS_MIN);
                    drawObject(highScoreText, 0, 4, 0, 0, SHIP_BRIGHTNESS_MIN);
                } else {
                    if (highScoreToggle & 1) {
                        drawObject(num3by4, highScoreLo * 4, 4, 0, 6, SHIP_BRIGHTNESS_MIN);
                        drawObject(num3by4, highScoreHi * 4, 4, 4, 6, SHIP_BRIGHTNESS_MIN);
                    } else {
                        drawObject(highScoreText, 0, 4, 0, 6, SHIP_BRIGHTNESS_MIN);
                    }
                    if (++highScoreCount > 15) {
                        highScoreCount = 0;
                        highScoreToggle++;
                        if (highScoreToggle & 1) {
                            drawObject(highScoreText, 0, 4, 0, 6, 0);
                        } else {
                            drawObject(num3by4, highScoreLo * 4, 4, 0, 6, 0);
                            drawObject(num3by4, highScoreHi * 4, 4, 4, 6, 0);
                        }
                    }
                }
            }
        } else {
            if (!gameOver) {
                drawSprite(sprite1, SHIP_BRIGHTNESS_MIN);
                if (bombHit) {
                    blinkSprite(sprite2, 4, BG_BRIGHTNESS_MIN, BG_BRIGHTNESS_MAX);
                } else {
                    drawSprite(sprite2, BG_BRIGHTNESS_MIN);
                }
                if (!dxBg) blinkSprite(sprite3, 2, THRUST_BRIGHTNESS_MIN, THRUST_BRIGHTNESS_MAX);
                if (bombActive) drawSprite(sprite4, BOMB_BRIGHTNESS_MIN);
                if (bombHit) blinkSprite(sprite4, 2, BOMB_BRIGHTNESS_MIN, BOMB_BRIGHTNESS_MAX);
            } else { // GAME OVER!!!!
                uint8_t shipExplodeFrame = 0;
                uint8_t drawOrErase = 0;
                drawSprite(sprite2, BG_BRIGHTNESS_MIN);
                bombNote = 16;
                for (uint16_t x = 0; x < 250; x++) {
                    if (x & 1) {
                        if (userInput) {
                            playNote(bombNote);
                        } else {
                            playNote(0);
                        }
                    } else {
                        playNote(0);
                    }
                    if ((x & 0x0f) == 0x0f) {   
                        if (shipExplodeFrame > 0) {
                            drawObject(shipExplosion, (shipExplodeFrame-1) * 5, 5, sprite1[SPRITE_DX_OFFSET], sprite1[SPRITE_DY_OFFSET]-1, 0);
                        } else {
                            drawObject(shipExplosion, 2 * 5, 5, sprite1[SPRITE_DX_OFFSET], sprite1[SPRITE_DY_OFFSET]-1, 0);
                        }
                        drawObject(shipExplosion, shipExplodeFrame * 5, 5, sprite1[SPRITE_DX_OFFSET], sprite1[SPRITE_DY_OFFSET]-1, SHIP_BRIGHTNESS_MAX);
                        drawSprite(sprite2, BG_BRIGHTNESS_MIN);
                        if (shipExplodeFrame < 2) {
                            shipExplodeFrame++;
                        } else {
                            shipExplodeFrame = 0;
                        }
                    }
                }
                ledClear(); // blank screen
                if (userInput) {
                    scoreCountGameOver = 80; // display final score
                    writeEEPROM(1, highScoreLo);
                    writeEEPROM(2, highScoreHi);
                } else {
                    playNote(0);
                    break; // EXIT GAME
                }
            }
        }
        
        delay(20); // Give each frame of visual data a bit of time to be displayed
        
        // Now erase objects to allow for them to be moved on the next frame
        if (scoreCount == 1) { // erase on last frame
            drawObject(num3by4, scoreLo * 4, 4, 0, 3, 0);
            drawObject(num3by4, scoreHi * 4, 4, 4, 3, 0);
        } else if (scoreCountGameOver) {
            // Don't erase this final score screen now, it just makes it flickery
        } else {
            eraseSprite(sprite1);
            eraseSprite(sprite2);
            if (!dxBg) eraseSprite(sprite3);
            if (bombActive || bombHit) eraseSprite(sprite4);
        }
        if (scoreCount) {
            scoreCount--;
        }
        if (scoreCountGameOver) {
            scoreCountGameOver--;
            if (scoreCountGameOver == 0) {
                if (gameOver) {
                    playNote(0);
                    break; // EXIT GAME
                } else {
                    if (highscoreOnBoot) {
                        highscoreOnBoot = 0;
                    }
                    ledClear(); // clear screen and start game
                }
            }
        }
      
        // move sprite1 (ship)
        if (dwellShip == 0) {
            if (++moveShip > dxShip) {
                moveShip = 0;
                if (dirShip) {
                    dxBg = BG_ACCELERATE_DX;
                    if (sprite1[SPRITE_DX_OFFSET] > 2) {
                        sprite1[SPRITE_DX_OFFSET] -= 1;
                        sprite3[SPRITE_DX_OFFSET] -= 1;
                    } else {
                        dirShip = 0;
                        dxShip = SHIP_ACCELERATE_DX;
                        dwellShip = SHIP_DWELL_FAST;
                        
                    }
                } else {
                    dxBg = BG_DECELERATE_DX;
                    if (sprite1[SPRITE_DX_OFFSET] < 6) {
                        sprite1[SPRITE_DX_OFFSET] += 1;
                        sprite3[SPRITE_DX_OFFSET] += 1;
                    } else {
                        dirShip = 1;
                        dxShip = SHIP_DECELERATE_DX;
                        dwellShip = SHIP_DWELL_SLOW;
                    }
                }
            }
        } else {
            dwellShip--;
        }
        
        // Read touch joystick
        if (RB0 == 0) {
            userInput = 1;

//            // Switch to next game if button held??
//            touchCount++;
//            if (touchCount > 100) {
//                ledClear(); // blank screen
//                drawSprite(nextSprite, BOMB_BRIGHTNESS_MIN);
//                delay(2000);
//                playNote(0);
//                break;
//            }

            if (++touchCount < 50) { // only allow rapid fire for about 3 shots
                // drop sprite4 (bomb)
                if (!bombHit && !bombActive) {
                    bombActive = 1;
                    bombCount = 0;
                    bombNote = G6; // fly like a G6!
                    playNote(bombNote);
                    sprite4[SPRITE_DX_OFFSET] = sprite3[SPRITE_DX_OFFSET];
                }
            }
        } else {
            touchCount = 0;
        }
        // Check fuel level
        if (fuel < 80) {
            if (fuel > 60) {
                sprite1[SPRITE_DY_OFFSET] = 1;
                sprite3[SPRITE_DY_OFFSET] = 1;
            } else if (fuel > 40) {
                sprite1[SPRITE_DY_OFFSET] = 2;
                sprite3[SPRITE_DY_OFFSET] = 2;
            } else if (fuel > 20) {
                sprite1[SPRITE_DY_OFFSET] = 3;
                sprite3[SPRITE_DY_OFFSET] = 3;
            } else if (fuel > 10) {
                sprite1[SPRITE_DY_OFFSET] = 4;
                sprite3[SPRITE_DY_OFFSET] = 4;
            } else {
                gameOver = 1;
            }
        } else {
            sprite1[SPRITE_DY_OFFSET] = 0;
            sprite3[SPRITE_DY_OFFSET] = 0;
        }
        if (bombActive) {
            if (++bombCount > bombRate[sprite4[SPRITE_DY_OFFSET]]) {
                bombCount = 0;
                if (sprite4[SPRITE_DY_OFFSET] > 8) {
                    playNote(0);
                    bombActive = 0;
                    // if bomb is at max depth right in line
                    // with mountain base, bomb hit!
                    // Mountain base peak offset = 2
                    if (isHitX(sprite4[SPRITE_DX_OFFSET], sprite2[SPRITE_DX_OFFSET], 3)) {
                        bombHit = 1;
                        bombCount = 0;
                        if (!dxBg) { // if moving fast, more reward!
                            scoreLo += 3;
                        } else {
                            scoreLo++;
                        }
                        if (scoreLo > 9) {
                            scoreLo -= 10;
                            scoreHi++;
                        }
                        if (scoreHi > highScoreHi || (scoreHi == highScoreHi && scoreLo > highScoreLo)) {
                            highScoreHi = scoreHi;
                            highScoreLo = scoreLo;
                        }
                    } else {
                        sprite4[SPRITE_DY_OFFSET] = 2;
                    }
                } else {
                    sprite4[SPRITE_DY_OFFSET] += 1;
                }
            }
            if (bombActive) {
                bombNote -= 25;
                playNote(bombNote);
            }
        }
        if (bombHit) {
            if (bombCount == 0) {
                bombNote = rand() & 0x3f + 50; // 50Hz ~ 113Hz
            }
            if (++bombCount & 1) {
                playNote(bombNote);
            } else {
                playNote(50);
            }
            if (bombCount > 30) {
                bombHit = 0;
                playNote(0);
                bombActive = 0;
                sprite4[SPRITE_DY_OFFSET] = 2;
                scoreCount = 20; // display score
                if (fuel < 175) {
                    fuel += 80; // refuel after score displayed
                }
            }
        }
        // move sprite2 (background)
        if (!bombHit && ++moveBg > dxBg) {
            moveBg = 0;
            if (sprite2[SPRITE_DX_OFFSET] < 6) {
                sprite2[SPRITE_DX_OFFSET] += 1;
                fuel--;
            } else {
                sprite2[SPRITE_DX_OFFSET] = 0;
            }
        }
    } // END SCRAMBLE
    
    } // END SUPER LOOP
} // main()

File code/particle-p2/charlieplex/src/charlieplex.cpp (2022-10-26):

#include "Particle.h"
#include "Particle_Adafruit_IS31FL3731.h"

SYSTEM_THREAD(ENABLED);

#define FRAMES_DEMO (0)

// If you're using the full breakout...
// Particle_Adafruit_IS31FL3731 ledmatrix = Particle_Adafruit_IS31FL3731();
// If you're using the FeatherWing version
Particle_Adafruit_IS31FL3731_Wing ledmatrix = Particle_Adafruit_IS31FL3731_Wing();


#if FRAMES_DEMO
// list of text to drawn on each frame
String frames[] = { "20", "21", "22", "23", "24", "25", "26", "27"}; // 8 frames max!
#else
// The lookup table to make the brightness changes be more visible
uint8_t sweep[] = { 1, 2, 3, 4, 6, 8, 10, 15, 20, 30, 40, 60, 60, 40, 30, 20, 15, 10, 8, 6, 4, 3, 2, 1 };
#endif // FRAMES_DEMO

void setup() {
    Serial.begin(9600);
    // delay(5000);
#if FRAMES_DEMO
    Serial.println("ISSI frames demo");
#else
    Serial.println("ISSI swirl test");
#endif // FRAMES_DEMO

    // call .begin(address) to initialize the driver.
    // .begin() will return false if the matrix was not found, and true if initialization succeeded
    if (!ledmatrix.begin()) {
        Serial.println("IS31 not found");
        while (1);
    }
    Serial.println("IS31 found!");

#if FRAMES_DEMO
    ledmatrix.setTextWrap(false);
    ledmatrix.setTextColor(32, 0);
    ledmatrix.setTextSize(1);

    // draw each frame
    for (size_t i = 0; i < arraySize(frames); ++i) {
        ledmatrix.setFrame(i);
        ledmatrix.setCursor(0, 0);
        ledmatrix.fillScreen(0);
        ledmatrix.print(frames[i]);
        Serial.printlnf("Frame: %i", i);
    }
#endif // FRAMES_DEMO
}

void loop() {
#if FRAMES_DEMO
    int count = arraySize(frames);
    int ms = 250;

    // display each frame for 250 milliseconds
    for (int i = 0; i < count; ++i) {
        ledmatrix.displayFrame(i);
        Serial.printlnf("Showing Frame: %i", i);
        delay(ms);
    }
    // now in reverse order
    for (int i = count - 2; i > 0; --i) {
        ledmatrix.displayFrame(i);
        Serial.printlnf("Showing Frame: %i", i);
        delay(ms);
    }
#else
    // // animate over all the pixels, and set the brightness from the sweep table
    // for (uint8_t incr = 0; incr < 24; incr++) {
    //     for (uint8_t x = 0; x < 10; x++) {
    //         for (uint8_t y = 0; y < 7; y++) {
    //             ledmatrix.drawPixel(x, y, sweep[(x + y + incr) % 24]);
    //         }
    //     }
    // }
    // delay(20);

    static int8_t counter = 0;
    // BOTTOM
    static uint8_t brightness = 30;
    for (int8_t x = 0; x < 7; x++) {
        if ((x + counter) % 4 == 0) {
            ledmatrix.drawPixel(9, x, brightness);
        } else {
            ledmatrix.drawPixel(9, x, 0);
        }
    }
    // RIGHT
    for (int8_t y = 0; y < 10; y++) {
        if ((y - counter) % 4 == 0) {
            ledmatrix.drawPixel(y, 6, brightness);
        } else {
            ledmatrix.drawPixel(y, 6, 0);
        }
    }
    // TOP
    for (int8_t x = 0; x < 7; x++) {
        if ((x - counter) % 4 == 0) {
            ledmatrix.drawPixel(0, x, brightness);
        } else {
            ledmatrix.drawPixel(0, x, 0);
        }
    }
    // LEFT
    for (int8_t y = 0; y < 10; y++) {
        if ((y + counter) % 4 == 0) {
            ledmatrix.drawPixel(y, 0, brightness);
        } else {
            ledmatrix.drawPixel(y, 0, 0);
        }
    }
    counter++;
    if (counter > 3) {
        counter = 0;
    }
    delay(20);
#endif // FRAMES_DEMO
}

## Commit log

2022-09-25 4 hours of work redone in 1 hour
    [vectrex-sao.kicad_pcb, vectrex-sao.kicad_sch]
2022-09-25 rearrange the bottom two rows
    [vectrex-sao.kicad_pcb, vectrex-sao.kicad_sch]
2022-09-28 rearranged parts, add temp silk, grid 2.54mm
    [vectrex-sao.kicad_pcb]
2022-10-01 finished outline, added controller board
    [vectrex-sao-B_Cu.gbl, vectrex-sao-B_Mask.gbs, vectrex-sao-B_Paste.gbp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]
2022-10-26 updated models and created files for ordering
    [vectrex-sao-B_Cu.gbl, vectrex-sao-B_Mask.gbs, vectrex-sao-B_Paste.gbp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]
2024-11-14 update to latest KiCAD 8.0.6
    [vectrex-sao-controller.kicad_sch, vectrex-sao.kicad_pcb, vectrex-sao.kicad_sch]
2024-11-15 update BOM and add coily cord construction pics
    [vectrex-sao.csv]
2024-11-15 add wire to BOM
    [vectrex-sao.csv]
2024-11-21 update BOM references to remove trailing ', ' and make LS2 DNP
    [vectrex-sao.csv]
2025-01-17 update files for easier mass production with JLCPCB
    [vectrex-sao-bom-both-sides.csv, vectrex-sao-bom-leds-only.csv, vectrex-sao.csv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]
